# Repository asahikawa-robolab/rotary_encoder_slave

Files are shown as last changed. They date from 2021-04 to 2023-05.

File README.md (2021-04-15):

# 概要
モータやエンコーダを使用するのに必要なプログラムをまとめたリポジトリ．下記のプログラムはすべて同一の基板で使用可能．
|プログラム|用途|
|:-|:-|
|pwm_control|デューティー比でモータを制御する|
|revolution_control|回転数でモータを制御する|
|rotation_angle_control|回転角でモータを制御する|
|odometry|接地エンコーダからオドメトリを取得する|
# リファレンス
* [pwm_control](doc/pwm_control.md)
* [revolution_control](doc/revolution_control.md)
* [rotation_angle_control](doc/rotation_angle_control.md)
* [odometry](doc/odometry.md)
# リポジトリ構成
```tree
├── circuit
│   ├── new -> 新版の基板データ ( eagle )
│   └── old -> 旧版の基板データ ( pcbe )
└── program
    ├── odometry.X ---------------> odometry のプログラム
    ├── pwm_control.X ------------> pwm_control のプログラム
    ├── revolution_control.X -----> revolution_control のプログラム
    └── rotation_angle_control.X -> rotation_angle_control のプログラム
```

# 動作確認環境
* IDE : MPLAB X IDE v4.15
* コンパイラ : XC16 v1.41
* コンパイルオプション : -std=c99
    * File -> Project Properties -> Categories: -> Conf: [default] -> XC16(Global Options) -> xc16-gcc -> Additional options: で指定
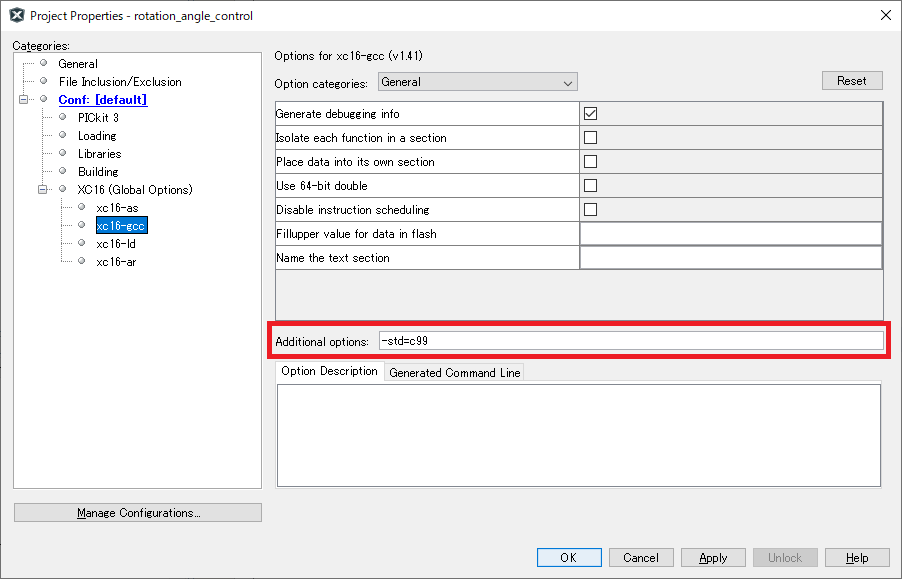
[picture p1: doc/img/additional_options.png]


# 基板の使用方法
# LEDについて
* 受信ができているときは高速で点滅する
* プログラムの実行中に深刻なエラーが発生したときは一定間隔で点滅する

# 回転量の符号について
* 本リポジトリのプログラムで登場する，「デューティー比，位置カウント，回転角，回転数」の符号は右ねじの法則に従っている．***モータ本体から軸に向かう向きに親指を向けたときの回転方向を正***と定義する．また，***正の方向に回転することを正転***と定義する．
* pwm_control を使って正のデューティ比でモータを駆動したとき，モータが正転しない場合はモータにはんだ付けされている線を入れ替えて回転方向を逆転させなければならない．
* モータの回転方向を逆転させるために，***プログラムで MD に出力する IO ピンを入れ替えないこと．*** 先のことを考えなければこれが一番簡単な方法だが，そのモータを使うときだけ他とは違うプログラムを使わなければならないことになる．これは経験上非常に面倒．

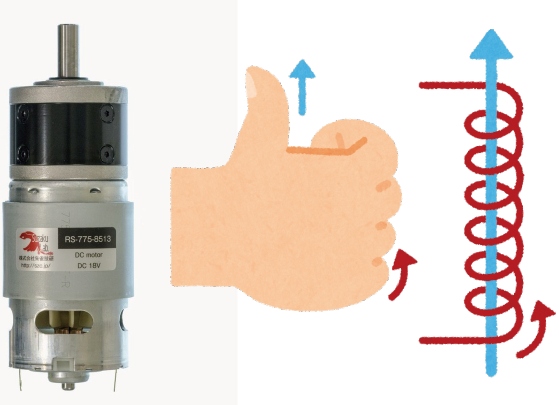
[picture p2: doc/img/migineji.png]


# QEI モジュールについて
* ***QEI ( Quadrature Encoder Interface)*** とは日本語で「直交エンコーダインターフェース」のことであり，端的に言えばエンコーダの信号をマイコンに読み込むためのモジュールである．
* 専用の回路を用意してハードウェアで処理しているタイプと，ソフトウェアで疑似的に QEI を実装しているタイプの２つがある．
* 後者のタイプはマイコンの処理が重くなると処理可能な周波数が下がってしまうため，***ハードウェアで実装されている QEI の使用を強く推奨する．***
* ピン変化割り込みを使用することで QEI モジュールを疑似的に実装することはできるが，処理可能な周波数が低すぎて使い物にならなかった．
### 参考
* [セクション 15. 直交エンコーダ インターフェイス(QEI)](http://ww1.microchip.com/downloads/jp/DeviceDoc/70208B_JP.pdf)

# 使用上の注意
# トラブルシューティング

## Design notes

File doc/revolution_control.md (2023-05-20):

# revolution_control
### フローチャート
<details><summary>表示</summary><div>

<br>

***※太字斜体下線の文字列はパラメータで設定する値***


* A : 出力デューティー比を決定する式．前回の値を使用しているため，「比例ゲイン」によって加減速の具合を調整できる．
* B : 出力デューティー比を既定の範囲内に収める処理．
* C : 非常停止を解除した際の急加速を防止する処理．
    * 非常停止などによって駆動電源が投入されていない状態で回転数偏差が生じると，駆動電源を投入したとき（非常停止を解除したとき）モータが急加速する可能性がある ( 詳細は「  」を参照 ) ．
    * そこで回転数現在値が「停止回転数」以下になったら駆動電源が投入されていない可能性があると判断して，「停止 PWM」を出力デューティー比の上限にする．
* D : 現在値と目標値の偏差の絶対値が閾値（ 10 [rpm] ）以下になったらモータを停止する．
    * 閾値に関して，変更されなさそうなのでパラメータとして設定できるようにはしていない．
* E : 「有効化」が 0 だったチャンネルはモータを駆動しない．誤作動を防ぐために，***使用しないチャンネルの「有効化」は 0 にすること．***
* F : 「エンコーダ極性」というパラメータが正しいか確認する処理．
    * 説明のために次の２つの語句を定義する．
        * 回転数実測値 : エンコーダから出力されるパルスから計算した回転数
        * 回転数現在値 : 「エンコーダ極性」が 0 のときは回転数実測値と等しい値，「エンコーダ極性」が 1 のときは回転数実測値に -1 を乗じた値．
    * このプログラムはモータが正転したとき ( デューティー比が正のとき ) に回転数現在値が正になる前提で書かれている．エンコーダの取り付けられている向きやギヤのかまされ方に応じてモータ正転時の回転数実測値の符号が変わるため，状況に応じて「エンコーダ極性」の値を適切に設定しなければならない．
    * 「エンコーダ極性」の値が不適切な場合（モータ正転時の回転数現在値が負になってしまう場合），常にプログラムの意図した方向とは逆の方向にモータが回転するため，以下のような流れで暴走してしまう．
        1. 偏差が生じるとモータを駆動して偏差の絶対値を小さくしようとする．
        2. プログラムが意図した方向とは逆の方向に回転してしまう．
        3. 偏差の絶対値が大きくなる．
        4. 偏差の絶対値に比例してモータの出力を上げるため，偏差の絶対値がさらに大きくなる
        5. 「PWM 最大値」になるまでモータの出力が上がる
* G : check_pol() の中核にあたる処理．
    * 出力デューティー比が「PWM 最大値」のときに偏差の絶対値が増加したら，err_cnt をインクリメントする．
* H : 「 G 」の条件を 4 回連続で満たしたら，「 F 」で説明した暴走状態だと判断して inform_err() を呼び出す．
* I : モータを停止して LED を一定の間隔で点滅させ，エラーが発生したことを通知する．
</details></div>

### 通信データ ( M->S )
    1. 書き込み禁止
    2. 目標回転数 1 上位 8 bit [ rpm ]
    3. 目標回転数 1 下位 8 bit [ rpm ]
    4. 目標回転数 2 上位 8 bit [ rpm ]
    5. 目標回転数 2 下位 8 bit [ rpm ]
### 通信データ ( S->M )
    1. 現在の回転数 1 上位 8 bit [ rpm ]
    2. 現在の回転数 1 下位 8 bit [ rpm ]
    3. 現在の回転数 2 上位 8 bit [ rpm ]
    4. 現在の回転数 2 下位 8 bit [ rpm ]
    5. 出力 PWM1 ( -100 ～ 100 )
    6. 出力 PWM2 ( -100 ～ 100 )
### パラメータ
    1. 有効化 ( 0 or 1 )
    2. PWM 最大値 ( 1 ～ 100 )
    3. 停止回転数 ( 1 ～ ) [ rpm ]
    4. 停止 PWM  ( 1 ～ 100 )
    5. 比例ゲイン ( 未使用時：0 / 使用時：1 ～ )
    6. エンコーダ極性 ( 0 or 1 )
    7. エンコーダ分解能 ( 1 ～ )
    8. エラー停止有効化 ( 0 or 1 )
<details><summary>詳細</summary><div>

* 有効化
    * 使用するときは 1 にする．
    * 使用しないときは 0 にしておく．
    * ***使用しないのに 1 にしおくと，エンコーダのコネクタから乗ったノイズによって誤動作が起こる可能性がある．***
* PWM 最大値
    * 制御基板から出力する PWM 波形 のデューティー比の最大値
    * 「PWM 最大値」よりも大きな値がマスターから指定された場合は，「PWM 最大値」が代わりに使用される
    * 極力小さな値を指定することで，マスター側のプログラムに不具合が生じてもモータの暴走を防ぐことができる
* 停止回転数
    * モータが停止したと判断する回転数の最大値を指定する．詳細はフローチャートの「 C 」を参照すること．
* 停止 PWM
    * モータが停止したと判断されたときのデューティー比の上限．詳細はフローチャートの「 C 」を参照すること．
* 比例ゲイン
    * 出力デューティー比を決定する際に使用する．
    * 詳細はフローチャートの「 A 」を参照すること．
    * 大きめの値に設定することによってモータの加減速処理を行うことが可能．ただし，***足回りを制御する際には比例ゲインは小さめにして加減速処理は別に実装する方が好ましい．*** 詳細は「[足回りの加減速処理について](#足回りの加減速処理について)」を参照すること．
* エンコーダ極性
    * エンコーダの取り付けられ方に応じて設定する．詳細はフローチャートの「 F 」を参照すること．
* エンコーダ分解能
    * 分解能（１回転で何パルス出力されるか）を指定する
    * 古いエンコーダ ( RE30E-300-213-1 ) は分解能 300，新しいエンコーダ ( AMT102-V ) は DIP スイッチで分解能を設定できる．（分解能 384 で使うことが多い）
    * 新しいエンコーダ ( AMT102-V ) に関して，DIP スイッチと分解能の関係を下図に示す．( [引用元](https://www.cuidevices.com/product/resource/amt10.pdf) )
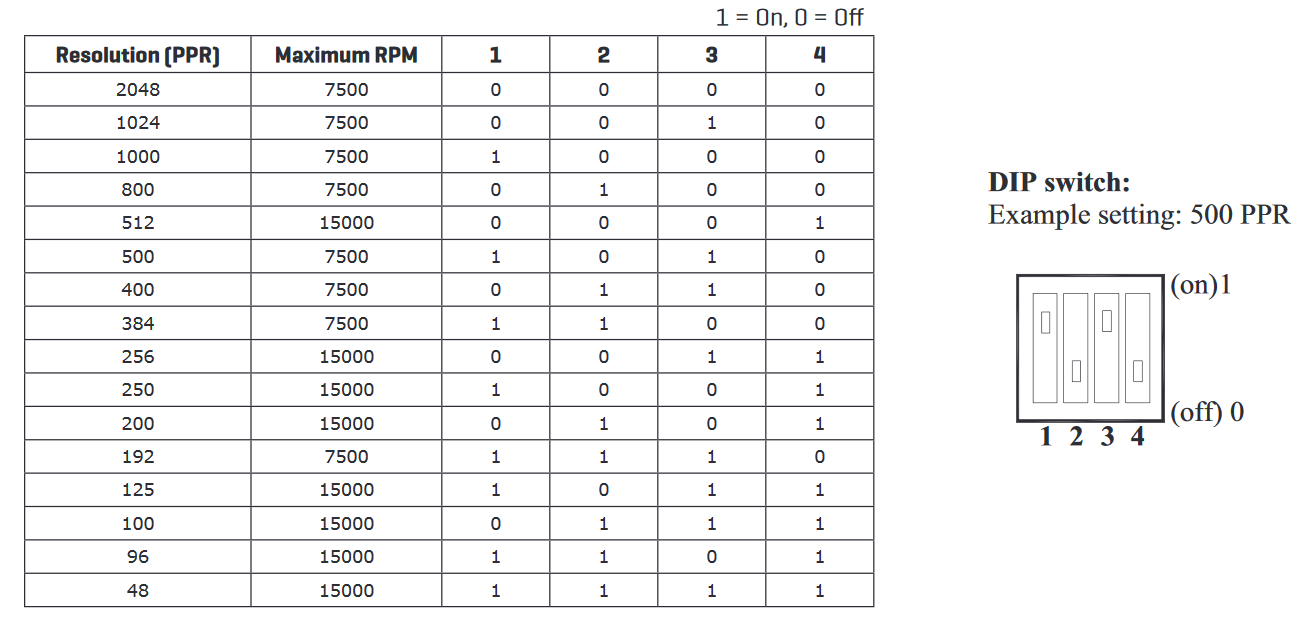
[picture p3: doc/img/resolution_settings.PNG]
    
* エラー停止有効化
    * 停止PWMを超えたときに最大PWM（停止PWM）を出力し続ける場合 0 にする．
    * 停止PWMを超えたときにエラーで停止する場合 1 にする．
    * どちらの場合でもエンコーダーの極性エラーの場合はエラーで停止する．
</div></details>

### 使用している周辺モジュール
|モジュール名|用途|
|:-|:-|
|UART1(TX, RX)|マスターとの通信|
|QEI1, QEI2|ロータリーエンコーダ|
|Timer1|フィードバック制御の計算周期の調整|
|Timer2|OC 用|
|OC1, OC2|DC モータを制御するための PWM|

### 足回りの加減速処理について

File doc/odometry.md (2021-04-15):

# odometry
### フローチャート
<details><summary>表示</summary><div>

<br>

***※太字斜体下線の文字列はパラメータで設定する値***


* A : reset_flag の値に応じて値をリセットする．
    * reset_flag は M → S の通信データの 2, 3 番目の「オドメトリ x リセット」を指す．
* B : POSxCNT のオーバーフローを考慮した位置カウントを算出する．
    * POSxCNT は 16 bit のレジスタなので g_qei_cnt に 65536( = 2^16) を乗じている．
* C : エンコーダの回転角度 ( odometry ) を算出する．
    * エンコーダが 1 回転すると「エンコーダ分解能 × 4」の位置カウントが生じる．つまり ( エンコーダ分解能 × 4.0 ) はエンコーダ 1 回転あたりの位置カウントを表す．
    * cnt ÷ ( エンコーダ分解能 × 4.0 ) はエンコーダが何回転したかを表す．これに 360.0 を乗じて [deg] に変換している．
* D : POSxCNT がオーバーフローした回数をカウントする．
    * 説明のために次の２つの語句を定義する．
        * 正のオーバーフロー : 変数の値の取り得る範囲を大きい側に超えること
        * 負のオーバーフロー : 変数の値の取り得る範囲を小さい側に超えること
    * POSxCNT は符号なしでサイズが 16bit の変数なので，値の取り得る範囲は 0 ～ 65535 (2^16 - 1)
    * 65535 + 1 = 65536 ( 0 ) は正のオーバーフロー
    * 0 - 1 = -1 ( 65535 ) は負のオーバーフロー
    * POSxCNT がオーバーフローしたときに QEI 割り込みが発生し，割り込み関数 ( QEI Interrupt ) が呼びだされる．
    * 正のオーバーフローによって QEI 割り込みが発生したとき，QEIxCONbits.UPDN は true に，負のオーバーフローのときは false になる．
    * 正のオーバーフローだったときは g_qei_cnt をインクリメント，負のオーバーフローだったときはディクリメントする．
</details></div>

### 通信データ ( M -> S )
    1. 書き込み禁止
    2. オドメトリ１リセット ( 0 : 通常時，1 : リセット )
    3. オドメトリ２リセット ( 0 : 通常時，1 : リセット )
    4. －
    5. －
### 通信データ ( S -> M )
    1. チャンネル１回転角度 1 ~ 8 bit [deg]
    2. チャンネル１回転角度 9 ~ 16 bit [deg]
    3. チャンネル１回転角度 17 ~ 24 bit [deg]
    4. チャンネル１回転角度 25 ~ 32 bit [deg]
    5. チャンネル２回転角度 1 ~ 8 bit [deg]
    6. チャンネル２回転角度 9 ~ 16 bit [deg]
    7. チャンネル２回転角度 17 ~ 24 bit [deg]
    8. チャンネル２回転角度 25 ~ 32 bit [deg]
### パラメータ
    1. エンコーダ極性 ( 0 or 1 )
    2. エンコーダ分解能 ( 1 ～ )
<details><summary>詳細</summary><div>

* エンコーダ極性
    * 1 にすると出力データの符号を反転する．エンコーダの取り付けられ方に応じて設定する．
* エンコーダ分解能
    * 分解能（１回転で何パルス出力されるか）を指定する
    * 古いエンコーダ ( RE30E-300-213-1 ) は分解能 300，新しいエンコーダ ( AMT102-V ) は DIP スイッチで分解能を設定できる．（分解能 384 で使うことが多い）
    * 新しいエンコーダ ( AMT102-V ) に関して，DIP スイッチと分解能の関係を下図に示す．( [引用元](https://www.cuidevices.com/product/resource/amt10.pdf) )
    
</div></details>

### 使用している周辺モジュール
|モジュール名|用途|
|:-|:-|
|UART1(TX, RX)|マスターとの通信|
|QEI1, QEI2|ロータリーエンコーダ|

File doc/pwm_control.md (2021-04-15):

# pwm_control
### フローチャート
<details><summary>表示</summary><div>

<br>

***※太字斜体下線の文字列はパラメータで設定する値***


* A : 出力デューティー比を既定の範囲内に収める処理．
* B : 「有効化」が 0 だったチャンネルはモータを駆動しない．誤作動を防ぐために，***使用しないチャンネルの「有効化」は 0 にすること．***
* C : MD への信号に変更を反映する処理．
    * この関数の内部で出力デューティー比の大きさを 100 以下に収める処理が行われている．
</details></div>

### 通信データ ( M->S )
    1. 書き込み禁止
    2. PWM1 ( -100 ～ 100 )
    3. PWM2 ( -100 ～ 100 )
    4. －
    5. －
### 通信データ ( S->M )
    1. －
### パラメータ
    1. 有効化 ( 0 or 1 )
    2. PWM 最大値 ( 1 ～ 100 )
    3. PWM 最大変化量（加減速処理） ( 1 ～ )
<details><summary>詳細</summary><div>

* 有効化
    * 使用するときは 1 にする．
    * 使用しないときは 0 にしておく．
    * ***使用しないのに 1 にしおくと，エンコーダのコネクタから乗ったノイズによって誤動作が起こる可能性がある．***
* PWM 最大値
    * 制御基板から出力する PWM 波形 のデューティー比の最大値
    * 「PWM 最大値」よりも大きな値がマスターから指定された場合は，「PWM 最大値」が代わりに使用される
    * 極力小さな値を指定することで，マスター側のプログラムに不具合が生じてもモータの暴走を防ぐことができる
* PWM 最大変化量
    * 1 秒あたりに許容するデューティー比の最大変化量
    * 100 を指定した場合は 1 秒間でデューティー比を 100% まで変化させられるため，停止状態のモータをデューティー比 100% で駆動させるまでに 1 秒かかる．
    * 50 を指定した場合は 1 秒間でデューティー比を 50% まで変化させられるため，停止状態のモータをデューティー比 100% で駆動させるまでに 2 秒かかる．
    * このようにしてモータの加減速処理をマイコン内部で実現できるため，マスター側は加減速処理を考えなくてよい．
</div></details>

### 使用している周辺モジュール
|モジュール名|用途|
|:-|:-|
|UART1(TX, RX)|マスターとの通信|
|Timer2 |OC 用|
|OC1, OC2 |DC モータを制御するための PWM|

# 改善点
* ~~加減速処理を追加して欲しい．~~
    * ~~rotation_angle_control の PARAM_MAX_PWM_CHANGE のようなパラメータを用意して pwm_control の内部で加減速処理を行う．~~
* ~~マスターでの加減速処理が不要になるからとても便利だと思う．~~
* ~~revolution_control のプログラムを使いまわしたら楽だと思う~~
    * ~~50ms 周期のタイマ割り込みが設定されているから~~

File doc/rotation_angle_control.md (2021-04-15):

# rotation_angle_control
### フローチャート
<details><summary>表示</summary><div>

<br>

***※太字斜体下線の文字列はパラメータで設定する値***


* A : ゼロ点合わせの処理にあたる．リミットスイッチが押されるとループを抜けて回転角制御の処理に移行する．
* B : 出力デューティー比を決定する式．ちなみに cnt_diff は「位置カウント目標値 - 位置カウント現在値」で求めている．
* C, D : 出力デューティー比を既定の範囲内に収める処理．
* E : 非常停止を解除した際の急加速を防止する処理．
    * 非常停止などによって駆動電源が投入されていない状態で回転角偏差が生じると，加減速処理が効力を発揮せず，駆動電源を投入すると（非常停止を解除すると）モータが急加速する可能性がある ( 詳細は「 G 」を参照 ) ．
    * そこで回転数現在値が「停止回転数」以下になったら駆動電源が投入されていない可能性があると判断して，「停止 PWM」を出力デューティー比の上限にする．
* F : 現在値と目標値の偏差の絶対値が「許容誤差」以下になったらモータを停止する．
* G : モータの加減速処理
    * 「 B 」式で出力デューティー比を計算しているため，回転角目標値を急激に変化させるなどして回転角偏差の絶対値が大きくなると，出力デューティー比が大きくなってモータが急加速する可能性がある．これを防ぐために単位時間当たりのデューティー比の変化量に制限を設けている（加減速処理）．
    * 加減速処理に関してはフィードバックを行っておらず，モータの状態に関係なく時間が経過すればデューティー比を大きくすることができる．したがって，「 E 」のように駆動電源が投入されている状態では加減速処理が機能しない．
* H : 「有効化」が 0 だったチャンネルはモータを駆動しない．誤作動を防ぐために，***使用しないチャンネルの「有効化」は 0 にすること．***
* I : 「エンコーダ極性」というパラメータが正しいか確認する処理．
    * 説明のために次の２つの語句を定義する．
        * 位置カウント実測値 : エンコーダから出力されるパルスから計算した位置カウント
        * 位置カウント現在値 : 「エンコーダ極性」が 0 のときは位置カウント実測値と等しい値，「エンコーダ極性」が 1 のときは位置カウント実測値に -1 を乗じた値．
    * このプログラムはモータが正転したとき ( デューティー比が正のとき ) に位置カウント現在値が増加する前提で書かれている．エンコーダの取り付けられている向きやギヤのかまされ方に応じてモータ正転時の位置カウント実測値の変化量の符号が変わるため，状況に応じて「エンコーダ極性」の値を適切に設定しなければならない．
    * 「エンコーダ極性」の値が不適切な場合（モータ正転時の位置カウント現在値が減少してしまう場合），常にプログラムの意図した方向とは逆の方向にモータが回転するため，以下のような流れで暴走してしまう．
        1. 偏差が生じるとモータを駆動して偏差の絶対値を小さくしようとする．
        2. プログラムが意図した方向とは逆の方向に回転してしまう．
        3. 偏差の絶対値が大きくなる．
        4. 偏差の絶対値に比例してモータの出力を上げるため，偏差の絶対値がさらに大きくなる
        5. 「PWM 最大値」になるまでモータの出力が上がる


* J : check_pol() の中核にあたる処理．
    * 出力デューティー比が「PWM 最大値」のときに偏差の絶対値が増加したら，err_cnt をインクリメントする．
* K : 出力デューティー比の符号が変わったら err_cnt をクリアする．
    * モータの回転方向が逆転するような回転角目標値が与えられたとき(*1)，「エンコーダ極性」が適切に設定されていたとしても「 J 」の条件を満たしてしまう可能性があるので，err_cnt をクリアする．
* L : 出力デューティー比の符号が変わらずに「 J 」の条件を 4 回連続で満たしたら，「 I 」で説明した暴走状態だと判断して inform_err() を呼び出す．
* M : モータを停止して LED を一定の間隔で点滅させ，エラーが発生したことを通知する．

*1 :<br>
例として回転角目標値が 1000 [deg], 回転角現在値が 500 [deg] で出力デューティー比が 70% のときに，回転角目標値を 0 [deg] に変更するとモータの回転方向が逆転する．
</details></div>

### 通信データ ( M->S )
    1. 書き込み禁止
    2. 目標回転角 1 上位 8 bit [ deg ]
    3. 目標回転角 1 下位 8 bit [ deg ]
    4. 目標回転角 2 上位 8 bit [ deg ]
    5. 目標回転角 2 下位 8 bit [ deg ]
### 通信データ ( S->M )
    1. 現在の回転角偏差 1 上位 8 bit [ deg ]
    2. 現在の回転角偏差 1 下位 8 bit [ deg ]
    3. 現在の回転角偏差 2 上位 8 bit [ deg ]
    4. 現在の回転角偏差 2 下位 8 bit [ deg ]
    5. 出力 PWM1 ( -100 ～ 100 )
    6. 出力 PWM2 ( -100 ～ 100 )
### パラメータ
    1. 有効化 ( 0 or 1 )
    2. ゼロ点合わせ PWM ( -100 ～ 100 )
    3. PWM 最大値 ( 1 ～ 100 )
    4. PWM 最小値 ( 1 ～ 100 )
    5. 停止回転数 ( 1 ～ ) [ rpm ]
    6. 停止 PWM ( 1 ～ 100 )
    7. PWM 変化量最大値 ( 1 ～ )
    8. 比例ゲイン ( 未使用時：0 / 使用時：1 ～ )
    9. 許容誤差 [ deg ]
    10. エンコーダ極性 ( 0 or 1 )
    11. エンコーダ分解能 ( 1 ～ )
<details><summary>詳細</summary><div>

* 有効化
    * 使用するときは 1 にする．
    * 使用しないときは 0 にしておく．
    * ***使用しないのに 1 にしおくと，エンコーダのコネクタから乗ったノイズによって誤動作が起こる可能性がある．***
* ゼロ点合わせ PWM
    * ゼロ点合わせ時に出力する PWM 波形のデューティー比
    * 負の値を指定することで回転方向を逆転させることができる
    * ゼロ点合わせ用のリミットスイッチが押された時点で急停止させるため，機械的，電気的にダメージの少ない小さめな値を指定すること
* PWM 最大値
    * 制御基板から出力する PWM 波形 のデューティー比の最大値
    * 「PWM 最大値」よりも大きな値がマスターから指定された場合は，「PWM 最大値」が代わりに使用される
    * 極力小さな値を指定することで，マスター側のプログラムに不具合が生じてもモータの暴走を防ぐことができる
* PWM 最小値
    * モータが回転するデューティー比の最小値を指定する
    * 目標値と現在値の偏差の絶対値が小さいときの微調整に使用する
* 停止回転数
    * モータが停止したと判断する回転数の最大値を指定する．詳細はフローチャートの「 E 」を参照すること．
* 停止 PWM
    * モータが停止したと判断されたときのデューティー比の上限．詳細はフローチャートの「 E 」を参照すること．
* PWM 変化量最大値
    * 加減速処理に使用するパラメータ
    * 許容する 1 秒あたりのデューティー比の変化量
    * 例としてこのパラメータを 50 に設定した場合，1 秒間で最大 50% だけデューティー比を変化させることができるため，停止状態（0%）から最大出力（100%）になるまで 2 秒かかることになる．
* 比例ゲイン
    * 出力デューティー比を決定する際に使用する．
    * 詳細はフローチャートの「 B 」を参照すること．
* 許容誤差
    * フィードバック制御で回転角現在値を回転角目標値に近づけていく際，許容する誤差．
    * 偏差が許容誤差以下になったらモータを停止させる．
* エンコーダ極性
    * エンコーダの取り付けられ方に応じて設定する．詳細はフローチャートの「 I 」を参照すること．
* エンコーダ分解能
    * 分解能（１回転で何パルス出力されるか）を指定する
    * 古いエンコーダ ( RE30E-300-213-1 ) は分解能 300，新しいエンコーダ ( AMT102-V ) は DIP スイッチで分解能を設定できる．（分解能 384 で使うことが多い）
    * 新しいエンコーダ ( AMT102-V ) に関して，DIP スイッチと分解能の関係を下図に示す．( [引用元](https://www.cuidevices.com/product/resource/amt10.pdf) )
    
</div></details>

### 使用している周辺モジュール
|モジュール名|用途|
|:-|:-|
|UART1(TX, RX)|マスターとの通信|
|QEI1, QEI2|ロータリーエンコーダ|
|Timer1|フィードバック制御の計算周期の調整|
|Timer2|OC 用|
|OC1, OC2|DC モータを制御するための PWM|
|入力変化通知|ゼロ点合わせのリミットスイッチの読み込み|

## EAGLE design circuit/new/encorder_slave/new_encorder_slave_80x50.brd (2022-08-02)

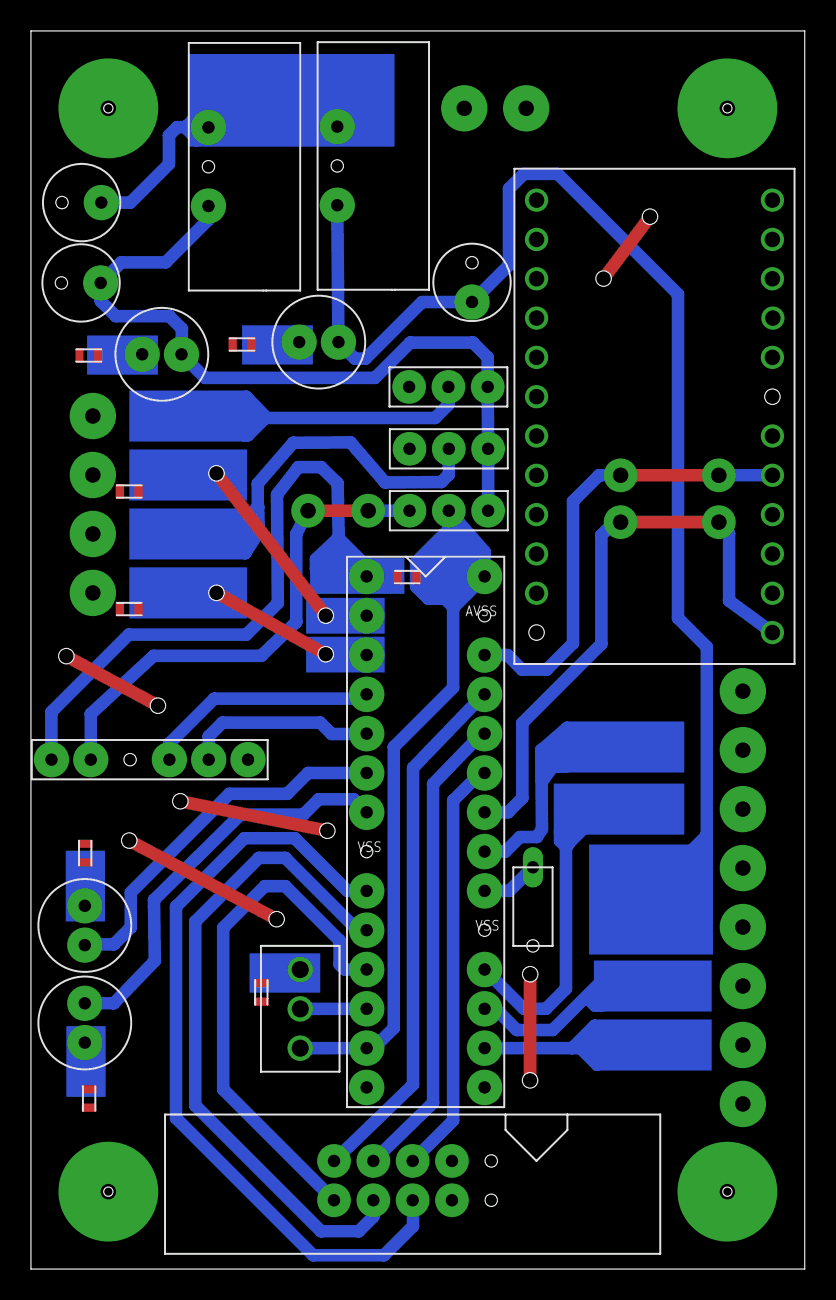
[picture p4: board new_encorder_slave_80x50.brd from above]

Board: 2 copper layers, 50.0 x 80.0 mm, 26 parts (0 on the bottom side), 17 nets.

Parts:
DSPIC33FJ128MC1: DSPIC33FJ128MC; PIC_28P_2
U$1, U$2, U$3, U$4: LED
U$5, U$16, U$17, U$18, U$19, U$20, U$21, U$23: CHIP_RESISTOR
U$6: TOGGLE_SWITCH(3PIN)
U$7: AE-UM232R
U$8: RIBBON_CABLE
U$9, U$10: REGULATOR
U$11: WRITER
U$12, U$13, U$14: CAPACITOR_33
U$15: CAPACITORS_106
U$24, U$25, U$26: 3PINSWITCH

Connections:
S$2: DSPIC33FJ128MC1.RB4, U$6.P$2
S$4: DSPIC33FJ128MC1.RB13, U$8.P$2
S$7: DSPIC33FJ128MC1.RB14, U$8.P$1
S$9: DSPIC33FJ128MC1.RA3, U$8.P$6
S$10: DSPIC33FJ128MC1.RA2, U$8.P$7
S$12: DSPIC33FJ128MC1.RA4, U$8.P$5
S$13: DSPIC33FJ128MC1.RB3, U$3.P$2
S$19: DSPIC33FJ128MC1.RB2, U$2.P$2
S$22: DSPIC33FJ128MC1.RB1, U$11.P$5
S$23: DSPIC33FJ128MC1.RB0, U$11.P$4
S$25: DSPIC33FJ128MC1.AVDD, DSPIC33FJ128MC1.VDD, U$6.P$1, U$24.P$2
S$26: DSPIC33FJ128MC1.MCLR, U$11.P$1
S$28: U$1.P$2, U$10.P$3, U$13.P$1
S$30: DSPIC33FJ128MC1.RB12, U$8.P$3
S$33: DSPIC33FJ128MC1.VCAP, U$15.P$2
S$41: U$4.P$1, U$9.P$3, U$12.P$1, U$24.P$3, U$25.P$3, U$26.P$3
S$56: U$9.P$2, U$14.P$1

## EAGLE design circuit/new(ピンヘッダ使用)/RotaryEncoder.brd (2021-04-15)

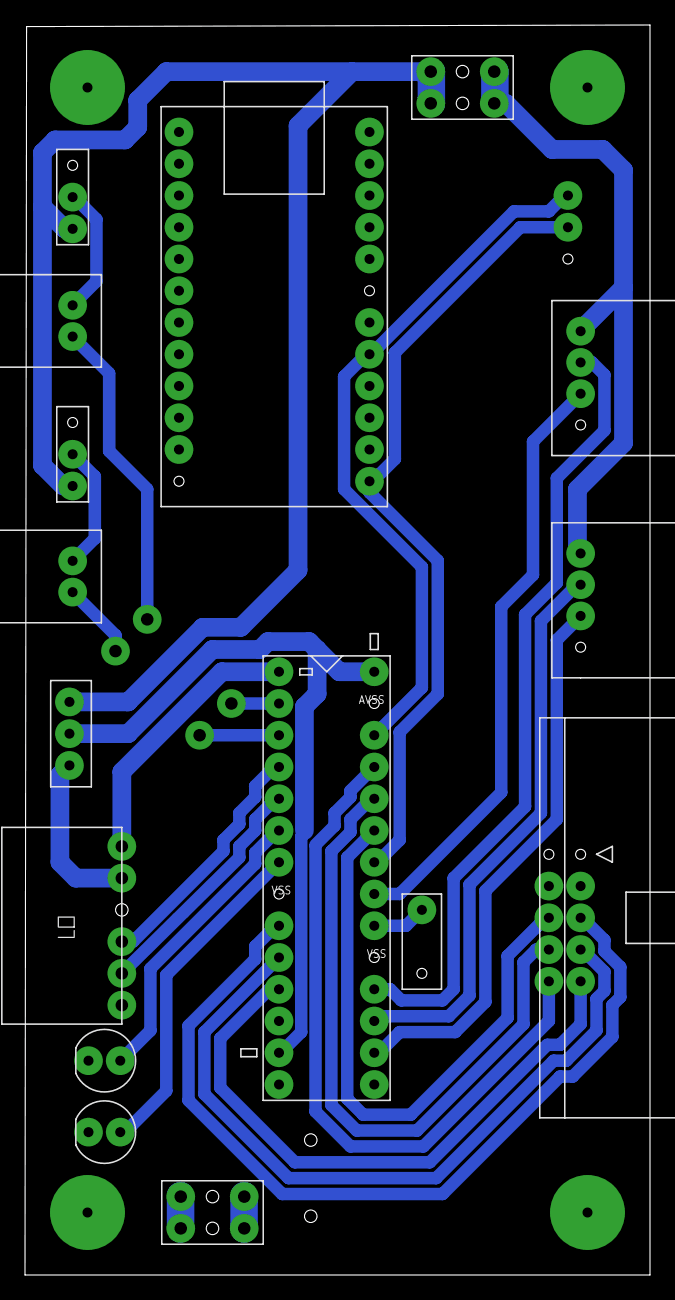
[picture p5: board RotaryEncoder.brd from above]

Board: 2 copper layers, 50.0 x 100.0 mm, 19 parts (0 on the bottom side), 13 nets.

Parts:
CAPACITOR1: CAPACITOR_VCAP; CAPACITOR_1
CHIP_CAPACITOR1, CHIP_CAPACITOR2: CHIP_CAPACITOR
CHIP_REGISTER1: CHIP_REGISTER
DSPIC33FJ128MC1: DSPIC33FJ128MC; PIC_28P_2
E$1: HIF3BD-10PA
E$2, E$3: PINHEADER_2*3
E$4: SLIDE_SWITCH_3
E$5: USB_SERIAL(FT232RL)
LED1, LED2: LED_1
PICKIT1: PICKIT3_L_REVERSE
SLIDE_SWITCH4, SLIDE_SWITCH5: SLIDE_SWITCH_3_A_GND
XH_SIDE_P3, XH_SIDE_P4: XH_SIDE_P4; XH_SIDE_4P
XH_SIDE_P5, XH_SIDE_P6: XH_SIDE_2P

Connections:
unnamed: DSPIC33FJ128MC1.RB1, PICKIT1.5
unnamed: DSPIC33FJ128MC1.RB2, LED1.A
unnamed: DSPIC33FJ128MC1.RB3, LED2.A
unnamed: DSPIC33FJ128MC1.RB13, E$1.4
S$1: DSPIC33FJ128MC1.RB4, E$1.1
S$2: CAPACITOR1.+, DSPIC33FJ128MC1.VCAP
S$8: E$4.2, PICKIT1.2
S$10: DSPIC33FJ128MC1.RA2, E$1.5
S$11: DSPIC33FJ128MC1.RB0, PICKIT1.4
S$18: DSPIC33FJ128MC1.MCLR, PICKIT1.1
S$19: DSPIC33FJ128MC1.RB11, E$5.TXD
S$23: DSPIC33FJ128MC1.RB15, E$5.RXD
S$28: DSPIC33FJ128MC1.RA3, E$1.3

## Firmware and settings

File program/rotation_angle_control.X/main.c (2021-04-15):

#define FCY 40000000UL /* delay 用 (Fosc/2) */
#include <libpic30.h>  /* delay */
#include <stdlib.h>
#include <xc.h>
#include <math.h>
#include "Controller_Protocol.h"
#include "dsPIC33FJ128MC802_config.h"
#include "dsPIC33FJ128MC802.h"
#include "general.h"
#include "config.h"
#include "setup.h"

/*-----------------------------------------------
 *
 * パラメータ
 *
-----------------------------------------------*/
typedef enum
{
    PARAM_ENABLE,
    PARAM_ZERO_POINT_PWM,
    PARAM_MAX_PWM,
    PARAM_MIN_PWM,
    PARAM_STOP_REV,
    PARAM_STOP_PWM,
    PARAM_PWM_CHANGE,
    PARAM_KP,
    PARAM_PERMISSIBLE_ERR,
    PARAM_ENCODER_POL,
    PARAM_ENCODER_RESOLUTION
} ParamList;

/*-----------------------------------------------
 *
 * 宣言
 *
-----------------------------------------------*/
void zero_point_pwm(double pwm[], size_t ch);
void calc_encoder(int64_t curr_cnt[], double curr_rev[], size_t ch);
void calc_rev(int64_t curr_cnt[], double curr_rev[], size_t ch);
void calc_pwm(int64_t curr_cnt[], int16_t angle_diff[], double curr_rev[], double pwm[], size_t ch);
int64_t calc_cnt_diff(int64_t curr_cnt[], int16_t angle_diff[], size_t ch);
void smoothen_pwm_change(double pwm[], size_t ch);
void check_pol(int16_t angle_diff[], double pwm[], size_t ch);
void inform_err(size_t ch);

/*-----------------------------------------------
 *
 * グローバル変数
 *
-----------------------------------------------*/
bool g_zero_point_done[2];                         /* ゼロ点合わせの状態 */
int64_t g_qei_int_cnt[2];                          /* QEI 割り込みが発生した回数 */
int16_t g_target_angle[2];                         /* 目標回転角 */
int16_t g_param[MAX_NUM_OF_PARAM][PARAM_UNIT_NUM]; /* パラメータ */

/*-----------------------------------------------
 *
 * main
 *
-----------------------------------------------*/
int main(int argc, char **argv)
{
    /* 初期設定 */
    Initialize_Parameters(); /* 通信ライブラリ初期化 */
    setup_dspic();
    setup_pin();
    setup_peripheral_module();

    /* パラメータ読み込み */
    load_param(g_param);

    while (1)
    {
        /* 受信 */
        Organize_Datas(RxData0, Buffer0, number_of_rxdata0, 0);
        g_target_angle[0] = ASBL(RxData0[1].all_data, RxData0[2].all_data);
        g_target_angle[1] = ASBL(RxData0[3].all_data, RxData0[4].all_data);

        /* 動作周期調整 */
        __delay_ms(5);
    }
    return (EXIT_SUCCESS);
}

/*-----------------------------------------------
 *
 * タイマ割り込み
 *
-----------------------------------------------*/
void __attribute__((interrupt, no_auto_psv)) _T1Interrupt(void)
{
    static size_t TmrIntCnt; /* タイマー割り込みの発生した回数 */

    T1IF = CLEAR;
    PR1 = TIMER_1MS;
    ++TmrIntCnt;

    /* CALC_PERIOD [ms] 毎に真になる */
    if (TmrIntCnt >= CALC_PERIOD)
    {
        TmrIntCnt = CLEAR;

        double pwm[2] = {0, 0}; /* 出力 PWM */
        double curr_rev[2];     /* 現在の回転数 */
        int64_t curr_cnt[2];    /* 現在の位置カウント */
        int16_t angle_diff[2];  /* 回転角偏差 */

        for (size_t i = 0; i < 2; ++i)
        {
            if (g_zero_point_done[i] == false)
            {
                zero_point_pwm(pwm, i);
            }
            else
            {
                calc_encoder(curr_cnt, curr_rev, i);              /* エンコーダに関する計算 */
                calc_pwm(curr_cnt, angle_diff, curr_rev, pwm, i); /* pwm を計算 */
                check_pol(angle_diff, pwm, i);                    /* エンコーダの極性の確認 */
            }
        }
        operate_motor(pwm); /* モータを操作 */

        /* 送信 */
        if (g_tx_flag)
        {
            TxData0[0] = UP(angle_diff[0]);
            TxData0[1] = LOW(angle_diff[0]);
            TxData0[2] = UP(angle_diff[1]);
            TxData0[3] = LOW(angle_diff[1]);
            TxData0[4] = (int8_t)pwm[0];
            TxData0[5] = (int8_t)pwm[1];
            Send_StartSignal(EUSART_Write, EUSART_TxInterrupt_Control, U2TXIE);
        }
    }
}

/*-----------------------------------------------
 *
 * QEI 割り込み
 *
-----------------------------------------------*/
void __attribute__((interrupt, no_auto_psv)) _QEI1Interrupt()
{
    if (QEI1CONbits.UPDN)
        ++g_qei_int_cnt[0];
    else
        --g_qei_int_cnt[0];
    QEI1IF = CLEAR;
}

void __attribute__((interrupt, no_auto_psv)) _QEI2Interrupt()
{
    if (QEI2CONbits.UPDN)
        ++g_qei_int_cnt[1];
    else
        --g_qei_int_cnt[1];
    QEI2IF = CLEAR;
}

/*-----------------------------------------------
 *
 * ピン変化割り込み
 *
-----------------------------------------------*/
void __attribute__((interrupt, no_auto_psv)) _CNInterrupt()
{
    CNIF = 0;

    if (ZERO_POINT1 & !g_zero_point_done[0])
    {
        /* モータ停止 */
        OC1RS = OC_PERIOD;
        MOTOR_F1 = 0;
        MOTOR_B1 = 0;

        /* クリア */
        g_qei_int_cnt[0] = CLEAR;
        POS1CNT = CLEAR;

        /* フラグセット */
        g_zero_point_done[0] = true;
    }
    if (ZERO_POINT2 & !g_zero_point_done[1])
    {
        /* モータ停止 */
        OC2RS = OC_PERIOD;
        MOTOR_F2 = 0;
        MOTOR_B2 = 0;

        /* クリア */
        g_qei_int_cnt[1] = CLEAR;
        POS2CNT = CLEAR;

        /* フラグセット */
        g_zero_point_done[1] = true;
    }
}

/*-----------------------------------------------
 *
 * 原点合わせ時の PWM
 *
-----------------------------------------------*/
void zero_point_pwm(double pwm[], size_t ch)
{
    /* エラーチェック */
    if (ch != 0 && ch != 1)
        inform_err(2);

    pwm[ch] = g_param[PARAM_ZERO_POINT_PWM][ch];

    /* PARAM_ENABLE が無効だったらモータを駆動しない */
    if (g_param[PARAM_ENABLE][ch] == false)
        pwm[ch] = 0;
}

/*-----------------------------------------------
 *
 * エンコーダに関する計算
 *
-----------------------------------------------*/
void calc_encoder(int64_t curr_cnt[], double curr_rev[], size_t ch)
{
    /* エラーチェック */
    if (ch != 0 && ch != 1)
        inform_err(2);

    /* 現在の位置カウントを計算 */
    if (ch == 0)
        curr_cnt[0] = (int64_t)(65536 * g_qei_int_cnt[0] + POS1CNT);
    else
        curr_cnt[1] = (int64_t)(65536 * g_qei_int_cnt[1] + POS2CNT);

    /* エンコーダの極性に合わせて反転 */
    if (g_param[PARAM_ENCODER_POL][ch] == 1)
        curr_cnt[ch] *= -1;

    /* 回転数を計算 */
    calc_rev(curr_cnt, curr_rev, ch);
}

/*-----------------------------------------------
 *
 * 回転数を計算
 *
-----------------------------------------------*/
void calc_rev(int64_t curr_cnt[], double curr_rev[], size_t ch)
{
    static int64_t pre_cnt[2]; /* 前回の位置カウント */

    /* 回転数を求めるときに使う係数を計算 */
    const double coef[2] = {
        1 / (g_param[PARAM_ENCODER_RESOLUTION][0] * 4.0) / (CALC_PERIOD * 1E-3) * 60.0,
        1 / (g_param[PARAM_ENCODER_RESOLUTION][1] * 4.0) / (CALC_PERIOD * 1E-3) * 60.0,
    };

    /* 回転数を計算 */
    curr_rev[ch] = (curr_cnt[ch] - pre_cnt[ch]) * coef[ch];

    /* 前回の位置カウントを更新 */
    pre_cnt[ch] = curr_cnt[ch];
}

/*-----------------------------------------------
 *
 * PWM を計算
 *
-----------------------------------------------*/
void calc_pwm(int64_t curr_cnt[], int16_t angle_diff[], double curr_rev[], double pwm[], size_t ch)
{
    /* エラーチェック */
    if (ch != 0 && ch != 1)
        inform_err(2);

    /* 位置カウント偏差を計算 */
    int64_t cnt_diff = calc_cnt_diff(curr_cnt, angle_diff, ch);

    /* 比例制御 */
    pwm[ch] = g_param[PARAM_KP][ch] * 1E-3 * cnt_diff +
              g_param[PARAM_MIN_PWM][ch] * GET_SIGNAL_INT(cnt_diff);
    pwm[ch] = (fabs(pwm[ch]) > g_param[PARAM_MAX_PWM][ch])
                  ? g_param[PARAM_MAX_PWM][ch] * GET_SIGNAL_FLOAT(pwm[ch])
                  : pwm[ch];

    /* -100 ～ 100 に収める */
    pwm[ch] = (fabs(pwm[ch]) > 100)
                  ? 100 * GET_SIGNAL_FLOAT(pwm[ch])
                  : pwm[ch];

    /* pwm が大きくても curr_rev が小さい場合，
        駆動が OFF であるとみなして pwm の上限を stop_pwm に制限する */
    if (fabs(curr_rev[ch]) < g_param[PARAM_STOP_REV][ch] && fabs(pwm[ch]) > g_param[PARAM_STOP_PWM][ch])
        pwm[ch] = g_param[PARAM_STOP_PWM][ch] * GET_SIGNAL_FLOAT(pwm[ch]);

    /* ある程度回転数が小さいときに偏差が許容誤差に収まったら停止 */
    if (abs(angle_diff[ch]) < g_param[PARAM_PERMISSIBLE_ERR][ch])
        pwm[ch] = 0;

    /* 加減速処理 */
    smoothen_pwm_change(pwm, ch);

    /* kp が 0 のときは停止 */
    if (g_param[PARAM_ENABLE][ch] == false)
        pwm[ch] = 0;
}

/*-----------------------------------------------
 *
 * 位置カウント偏差を計算
 *
-----------------------------------------------*/
int64_t calc_cnt_diff(int64_t curr_cnt[], int16_t angle_diff[], size_t ch)
{
    /* エラーチェック */
    if (ch != 0 && ch != 1)
        inform_err(2);

    /* 目標値を回転角から位置カウントに変換 */
    int64_t target_cnt = g_target_angle[ch] / 360.0 * g_param[PARAM_ENCODER_RESOLUTION][ch] * 4.0;

    /* 位置カウント偏差を計算 */
    int64_t cnt_diff = target_cnt - curr_cnt[ch];

    /* 位置カウント偏差を回転角偏差に変換 */
    angle_diff[ch] = cnt_diff / (g_param[PARAM_ENCODER_RESOLUTION][ch] * 4.0) * 360.0;

    return cnt_diff;
}

/*-----------------------------------------------
 *
 * 加減速処理
 *
-----------------------------------------------*/
void smoothen_pwm_change(double pwm[], size_t ch)
{
    const double max_change[2] = {
        g_param[PARAM_PWM_CHANGE][0] * CALC_PERIOD * 1E-3,
        g_param[PARAM_PWM_CHANGE][1] * CALC_PERIOD * 1E-3,
    };

    static double pre_pwm[2]; /* 前回の PWM */

    /* 変化量を計算 */
    double pwm_change = pwm[ch] - pre_pwm[ch];

    /* 変化量が大きかったら閾値に収める */
    if (fabs(pwm_change) > max_change[ch])
        pwm[ch] = pre_pwm[ch] + max_change[ch] * GET_SIGNAL_FLOAT(pwm_change);

    /* 更新 */
    pre_pwm[ch] = pwm[ch];
}

/*-----------------------------------------------
 *
 * エンコーダの極性を確認する
 *
-----------------------------------------------*/
void check_pol(int16_t angle_diff[], double pwm[], size_t ch)
{
    static size_t err_cnt[2];
    static int16_t pre_angle_diff[2];
    static double pre_pwm[2];

    /* エラーチェック */
    if (ch != 0 && ch != 1)
        inform_err(2);

    /* 偏差の変化量 */
    int16_t diff_change = abs(angle_diff[ch]) - abs(pre_angle_diff[ch]);

    /* 最大 PWM 出力時に回転角偏差が大きくなったら */
    bool c1 = (diff_change > 0);
    bool c2 = (g_param[PARAM_ENABLE][ch] == true);
    bool c3 = (fabs(pwm[ch]) == g_param[PARAM_MAX_PWM][ch]);

    if (c1 & c2 & c3)
        ++err_cnt[ch];
    else
        err_cnt[ch] = CLEAR;

    /* モータの回転方向が変わったら */
    if (pwm[ch] * pre_pwm[ch] < 0)
        err_cnt[ch] = CLEAR;

    /* 連続で条件を満たしたら停止 */
    if (err_cnt[ch] > 3)
        inform_err(ch);

    /* 更新 */
    pre_pwm[ch] = pwm[ch];
    pre_angle_diff[ch] = angle_diff[ch];
}

/*-----------------------------------------------
 *
 * LED を点滅させてエラーを知らせる
 *
-----------------------------------------------*/
void inform_err(size_t ch)
{
    /* モータを停止 */
    MOTOR_F1 = OFF;
    MOTOR_B1 = OFF;
    MOTOR_F2 = OFF;
    MOTOR_B2 = OFF;

    /* LED を光らせてエラーを知らせる */
    if (ch == 0)
    {
        while (1)
        {
            debug_LED1 = ON;
            __delay_ms(100);
            debug_LED1 = OFF;
            __delay_ms(100);
            debug_LED1 = ON;
            __delay_ms(100);
            debug_LED1 = OFF;
            __delay_ms(400);
        }
    }
    else if (ch == 1)
    {
        while (1)
        {
            debug_LED2 = ON;
            __delay_ms(100);
            debug_LED2 = OFF;
            __delay_ms(100);
            debug_LED2 = ON;
            __delay_ms(100);
            debug_LED2 = OFF;
            __delay_ms(400);
        }
    }
    else
    {
        while (1)
        {
            debug_LED1 = ON;
            debug_LED2 = ON;
            __delay_ms(100);
            debug_LED1 = OFF;
            debug_LED2 = OFF;
            __delay_ms(100);
            debug_LED1 = ON;
            debug_LED2 = ON;
            __delay_ms(100);
            debug_LED1 = OFF;
            debug_LED2 = OFF;
            __delay_ms(400);
        }
    }
}

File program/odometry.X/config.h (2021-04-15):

#ifndef CONFIG_H
#define CONFIG_H

/* debug */
#define debug_LED1 LATB3
#define debug_LED2 LATB2

/* timer1 interrupt */
#define TIMER_1MS 39201 /* 1 [ms] 分のカウント */
#define CALC_PERIOD 50  /* 計算を行う周期 [ms] */

/* OC */
#define OC_PERIOD 0x0800

/* motor ( 右ねじの方向が正転になるように選ぶ ) */
#define MOTOR_F1 LATA2
#define MOTOR_B1 LATB12
#define MOTOR_F2 LATA3
#define MOTOR_B2 LATB13

#endif

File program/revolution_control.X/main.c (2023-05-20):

#define FCY 40000000UL /* delay 用 (Fosc/2) */
#include <libpic30.h>  /* delay */
#include <stdlib.h>
#include <xc.h>
#include <math.h>
#include "Controller_Protocol.h"
#include "dsPIC33FJ128MC802_config.h"
#include "dsPIC33FJ128MC802.h"
#include "general.h"
#include "config.h"
#include "setup.h"

/*-----------------------------------------------
 *
 * パラメータ
 *
-----------------------------------------------*/
typedef enum
{
    PARAM_ENABLE,
    PARAM_MAX_PWM,
    PARAM_STOP_REV,
    PARAM_STOP_PWM,
    PARAM_KP,
    PARAM_ENCODER_POL,
    PARAM_ENCODER_RESOLUTION,
    PARAM_ERROR_STOP,
    PARAM_MAX_RPM
} ParamList;

/*-----------------------------------------------
 *
 * 宣言
 *
-----------------------------------------------*/
extern void Initialize(void);
void calc_encoder(double curr_rev[]);
void calc_rev(int64_t curr_cnt[], double curr_rev[]);
void calc_pwm(double pwm[], double curr_rev[]);
void check_pol(double pwm[]);
void inform_err(size_t ch);

/*-----------------------------------------------
 *
 * グローバル変数
 *
-----------------------------------------------*/
int64_t g_qei_int_cnt[2];                          /* QEI割り込みが発生した回数 */
int16_t g_target_rev[2];                           /* 目標回転数 */
int16_t g_param[MAX_NUM_OF_PARAM][PARAM_UNIT_NUM]; /* パラメータ */

/*-----------------------------------------------
 *
 * main
 *
-----------------------------------------------*/
int main(int argc, char **argv)
{
    /* 初期設定 */
    Initialize_Parameters(); /* 通信ライブラリ初期化 */
    setup_dspic();
    setup_pin();
    setup_peripheral_module();

    /* パラメータ読み込み */
    load_param(g_param);

    while (1)
    {
        /* 受信 */
        Organize_Datas(RxData0, Buffer0, number_of_rxdata0, 0);
        g_target_rev[0] = ASBL(RxData0[1].all_data, RxData0[2].all_data);
        g_target_rev[1] = ASBL(RxData0[3].all_data, RxData0[4].all_data);

        /* 動作周期調整 */
        __delay_ms(5);
    }
    return (EXIT_SUCCESS);
}

/*-----------------------------------------------
 *
 * タイマ割り込み
 *
-----------------------------------------------*/
void __attribute__((interrupt, no_auto_psv)) _T1Interrupt(void)
{
    static size_t TmrIntCnt; /* タイマー割り込みの発生した回数 */

    T1IF = CLEAR;
    PR1 = TIMER_1MS;
    ++TmrIntCnt;

    /* CALC_PERIOD [ms] 毎に真になる */
    if (TmrIntCnt >= CALC_PERIOD)
    {
        TmrIntCnt = CLEAR;

        double pwm[2];      /* 出力 PWM */
        double curr_rev[2]; /* 現在の回転数 */

        calc_encoder(curr_rev);  /* エンコーダに関する計算 */
        calc_pwm(pwm, curr_rev); /* pwm を計算 */
        check_pol(pwm);          /* エンコーダの極性の確認 */
        operate_motor(pwm);      /* モータを操作 */

        /* 送信 */
        if (g_tx_flag)
        {
            TxData0[0] = UP(curr_rev[0]);
            TxData0[1] = LOW(curr_rev[0]);
            TxData0[2] = UP(curr_rev[1]);
            TxData0[3] = LOW(curr_rev[1]);
            TxData0[4] = (int8_t)pwm[0];
            TxData0[5] = (int8_t)pwm[1];
            Send_StartSignal(EUSART_Write, EUSART_TxInterrupt_Control, U2TXIE);
        }
    }
}

/*-----------------------------------------------
 *
 * QEI 割り込み
 *
-----------------------------------------------*/
void __attribute__((interrupt, no_auto_psv)) _QEI1Interrupt()
{
    if (QEI1CONbits.UPDN)
        ++g_qei_int_cnt[0];
    else
        --g_qei_int_cnt[0];
    QEI1IF = CLEAR;
}

void __attribute__((interrupt, no_auto_psv)) _QEI2Interrupt()
{
    if (QEI2CONbits.UPDN)
        ++g_qei_int_cnt[1];
    else
        --g_qei_int_cnt[1];
    QEI2IF = CLEAR;
}

/*-----------------------------------------------
 *
 * エンコーダに関する計算
 *
-----------------------------------------------*/
void calc_encoder(double curr_rev[])
{
    /* 現在の位置カウントを計算 */
    int64_t curr_cnt[2];
    curr_cnt[0] = (int64_t)(65536 * g_qei_int_cnt[0] + POS1CNT);
    curr_cnt[1] = (int64_t)(65536 * g_qei_int_cnt[1] + POS2CNT);

    /* エンコーダの極性に合わせて反転 */
    for (size_t i = 0; i < 2; ++i)
    {
        if (g_param[PARAM_ENCODER_POL][i])
            curr_cnt[i] *= -1;
    }

    /* 回転数を計算 */
    calc_rev(curr_cnt, curr_rev);
}

/*-----------------------------------------------
 *
 * 回転数を計算
 *
-----------------------------------------------*/
void calc_rev(int64_t curr_cnt[], double curr_rev[])
{
    static int64_t pre_cnt[2]; /* 前回の位置カウント */

    /* 回転数を求めるときに使う係数を計算 */
    const double coef[2] = {
        1 / (g_param[PARAM_ENCODER_RESOLUTION][0] * 4.0) / (CALC_PERIOD * 1E-3) * 60.0,
        1 / (g_param[PARAM_ENCODER_RESOLUTION][1] * 4.0) / (CALC_PERIOD * 1E-3) * 60.0,
    };

    /* 回転数を計算 */
    for (size_t i = 0; i < 2; ++i)
        curr_rev[i] = (curr_cnt[i] - pre_cnt[i]) * coef[i];

    /* 前回の位置カウントを更新 */
    for (size_t i = 0; i < 2; ++i)
        pre_cnt[i] = curr_cnt[i];
}

/*-----------------------------------------------
 *
 * PWM を計算
 *
-----------------------------------------------*/
void calc_pwm(double pwm[], double curr_rev[])
{
    static double pre_pwm[2];  /* 前回の pwm */
    static int16_t pre_rev[2]; /* 前回の pwm */
    debug_LED2 = false;

    for (size_t i = 0; i < 2; ++i)
    {
        if (fabs(g_target_rev[i]) > g_param[PARAM_MAX_RPM][i])
        {
            debug_LED2 = true;
            g_target_rev[i] = pre_rev[i];
        }
        else
        {
            pre_rev[i] = g_target_rev[i];
        }

        /* エンコーダーの値が異常だったら前回のPWMにする */
        if (fabs(curr_rev[i]) > 5000 && pre_pwm[i] != 0)
            pwm[i] = pre_pwm[i];
        else
            /* 比例制御 */
            pwm[i] = pre_pwm[i] + (g_target_rev[i] - curr_rev[i]) * g_param[PARAM_KP][i] * 1E-2;

        /* -100 ～ 100 に収める */
        pwm[i] = (fabs(pwm[i]) > 100)
                     ? 100 * GET_SIGNAL_FLOAT(pwm[i])
                     : pwm[i];

        /* pwm が大きくても curr_rev が小さい場合，
        駆動が OFF であるとみなして pwm の上限を stop_pwm に制限する */
        if (fabs(curr_rev[i]) < g_param[PARAM_STOP_REV][i] && fabs(pwm[i]) > g_param[PARAM_STOP_PWM][i])
            pwm[i] = g_param[PARAM_STOP_PWM][i] * GET_SIGNAL_FLOAT(pwm[i]);

        /* 回転数の偏差が閾値以下で，目標回転数がが０だったらモータを停止 */
        if (fabs(g_target_rev[i] - curr_rev[i]) < 10 && g_target_rev[i] == 0)
            pwm[i] = 0;

        /* kp が 0 のときは停止 */
        if (g_param[PARAM_ENABLE][i] == false)
            pwm[i] = 0;

        /* 前回の pwm を更新 */
        if (!(fabs(curr_rev[i]) > 5000 && pre_pwm[i] != 0))
            pre_pwm[i] = pwm[i];
    }
}
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

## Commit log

2020-03-14 2019 年全国大会終了直後
    [根本]回転数、回転角、接地エンコーダ用基板
    ・回転角制御用のリミットを追加
    ・リミットだけでなくレーザーでも使えるようにスイッチをつけています。
    [太田]GitHubに初アップロード
    ・回転数制御の完成版
    [太田]GitHubに初アップロード
    ・PIDと単調加速の切り替えポイント修正
    [太田]ゼロ点合わせ以外の処理が一通りできるようになった。
    ・正転、逆転ともに収束はするものの、収束値が3°ずれる
    ・通信がまだ不安定かもしれない
    [太田]ゼロ点合わせの処理を追加した。
    ・基板未完成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
    [main.c]
2020-03-14 パラメータ設定に対応
    ◍ Raspberry Pi からパラメータを設定できるようにした
    ◍ README を追加
    [太田]基板の回路図を追加した
    [根本]Eagleで作った基板を追加
    ・Eagleで作った基板を追加
    [地引] ディレクトリを整理
    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
    [RotaryEncoder.brd, Rotary_Encoder.sch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]
2020-03-14 revolution_control のフローチャートを作成
2020-03-18 PARAM_ENABLE を追加
    ◍ pwm_control, revolution_control, rotation_angle_control に PARAM_ENABLE を追加．
    ◍ 受信割り込みでデバック LDE を点滅させるように変更．
    ◍ revolution_control と rotation_angle_control は一部パラメータの順番を入れ替えた．
    ◍ パラメータの並べ替えに対応させた
2020-03-18 rev と rot のフローチャート，パラメータ詳細完成
2020-03-18 odometry.md が完成
    ◍ QEI モジュールに関する補足説明を追加．
    ◍ pwm_control.md にフローチャートを追加．
    ◍ odometry に PARAM_ENCODER_POL の処理を実装．動作未確認．
    ◍ pwm_control にデューティー比の大きさを 100 以下に収める処理を追加．
2020-03-18 GET_SIGNAL で 0 除算が発生しないようにした
2020-03-18 pwm_conrtol の説明を追加
2020-03-24 additional_options の写真を修正
2020-08-31 pwm_control に加減速処理を実装
    commit 7756290a4ae4a987a20a9126475dee8c7837efc9
    Author: Takuto Jibiki <eipuuuuk825@gmail.com>
    Date: Mon Aug 31 16:57:51 2020 +0900
    マージする準備
    ◍ 加減速処理の動画を削除
    ◍ オートフォーマットをかけた
    ◍ pwm_control のプログラムのコメントを修正
    commit 590e21804a1fb4968d8ee7ce8ed877ab6c31418c
    Author: masato oohira <ohiram590@gmail.com>
    Date: Tue Jul 7 16:35:40 2020 +0900
    マスターから渡された最大変化量を/20し微調整できるようにした
    commit f10d5663248d43ac527cc6bcdc790de90efc9f2b
    Author: masato oohira <ohiram590@gmail.com>
    Date: Thu Jul 2 15:51:07 20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
    [config.h, general.c, main.c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]
2020-08-31 pwm_control.md のパラメータに関する記述を変更
2020-09-26 [大平]pwmを計算する回数の訂正
    ・繰り返し回数が1のみだったため1chしか出力されない状況だった
2022-07-11 エラー停止機能有効/無効切り替え機能の追加
    ・停止PWMを超えた場合に停止せずに最大PWMを出力し続ける機能を追加．
    ・その場合でもエンコーダーの極性エラーもチェックする．
    ・従来との切り替えのためのパラメータ追加
2022-07-28 pwmの値が非数だったら0 にするように変更
    ・駆動をONにした後にエンコーダースレーブを起動した時に暴走するバグを修正
2022-08-01 エンコーダーの値がおかしければ無視するように変更
2022-08-02 eagle用の基板データの追加
    [RotaryEncoder.brd, Rotary_Encoder.sch, new_encorder_slave 100x50 .brd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]
2022-08-02 基板が間違っていたため上げなおし
    [new_encorder_slave 100x50 .brd, new_encorder_slave_80x50.brd, new_encorder_slave_ver_adachi_80x50.brd]
2022-10-09 変更 ・rpmの上限のパラメータを追加して外れ値が入ると無視するように変更
2023-08-09 回転数を送るように変更
